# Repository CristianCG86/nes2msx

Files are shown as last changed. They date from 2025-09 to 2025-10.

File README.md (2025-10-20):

# NES2MSX

## Description
Converter for NES controllers (7-pin connector) to MSX standard.

## Acknowledgments
- David A. Mellis for his ATtiny board library (https://github.com/damellis/attiny).
- Josh Marinacci for his NESpad library (https://github.com/joshmarinacci/nespad-arduino).

## Why?
This project was born out of the difficulty of finding comfortable and accessible (and also affordable 🤑) controllers for MSX computers.  
But instead of destroying a NES controller, I decided to make this converter — that way I could also use other NES-style controllers such as those from 8Bitdo.

## Images
### PCB
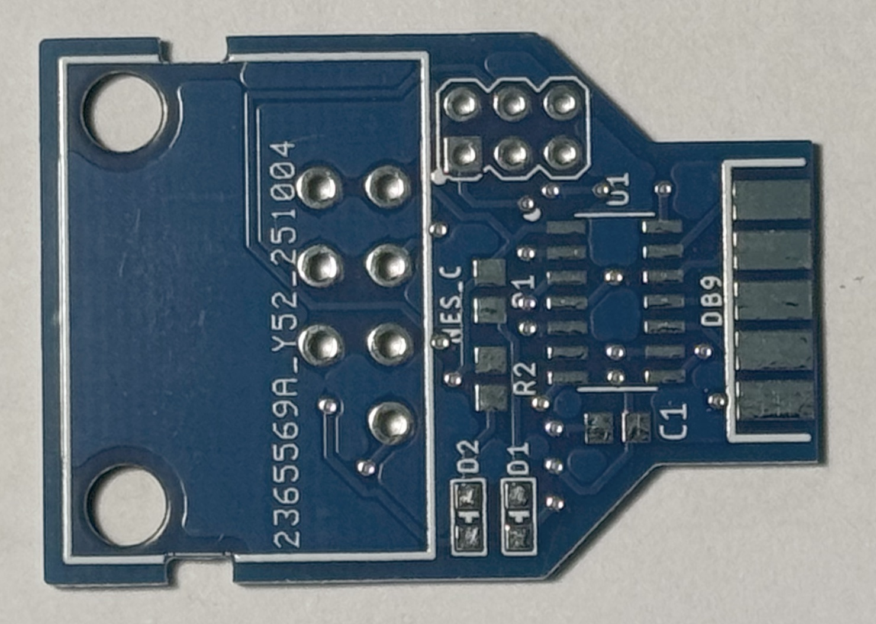
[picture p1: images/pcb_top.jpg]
PCB top side
  
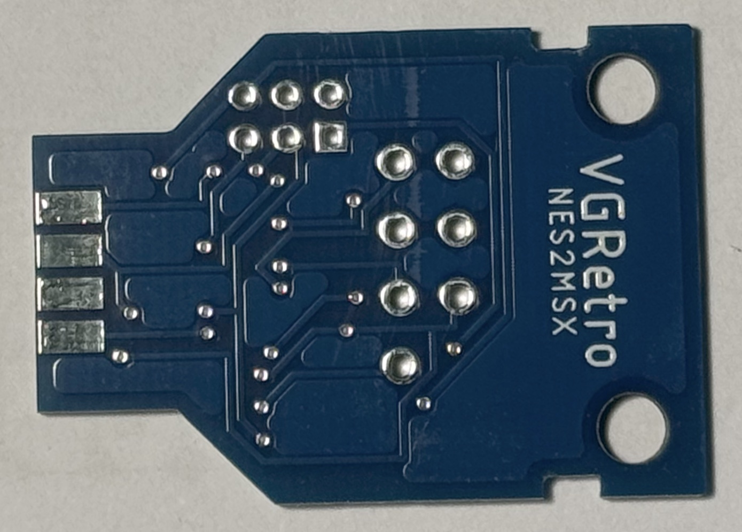
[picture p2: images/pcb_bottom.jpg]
PCB bottom side

### Assembled PCB
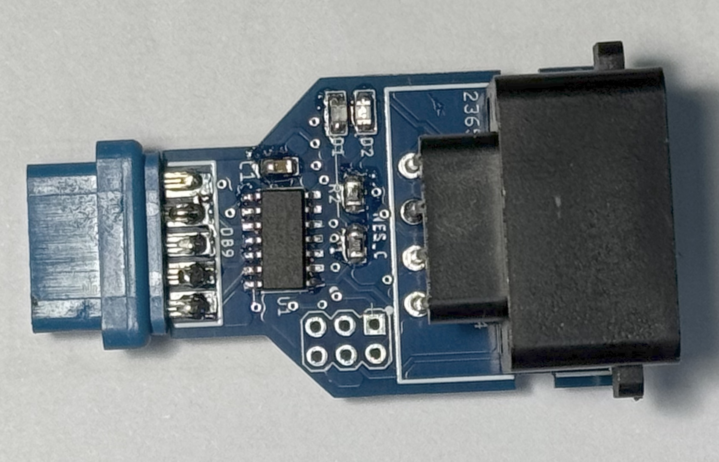
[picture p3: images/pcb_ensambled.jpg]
Assembled PCB top side


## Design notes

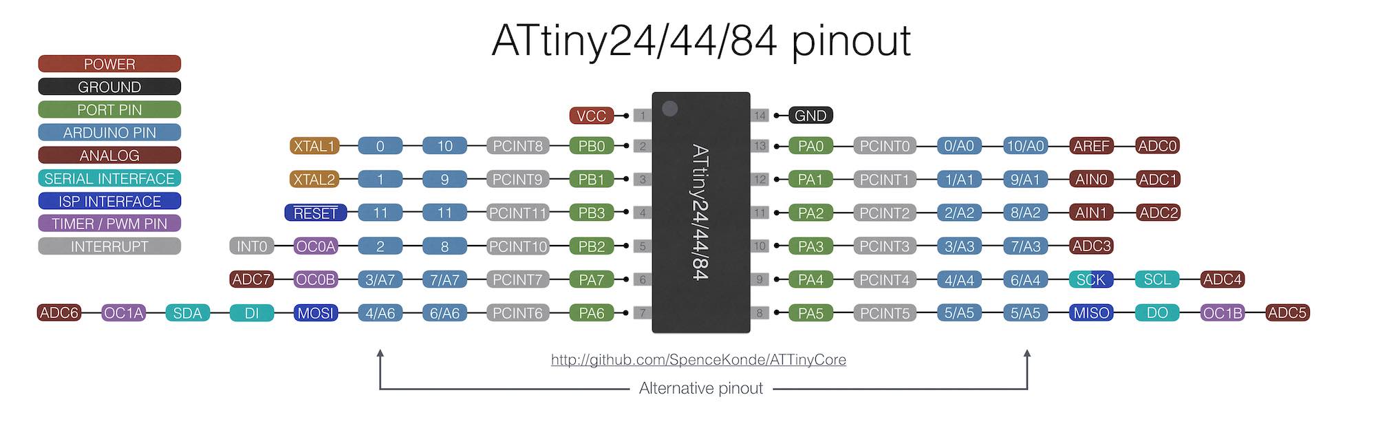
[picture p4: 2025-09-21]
attiny84_core.jpeg

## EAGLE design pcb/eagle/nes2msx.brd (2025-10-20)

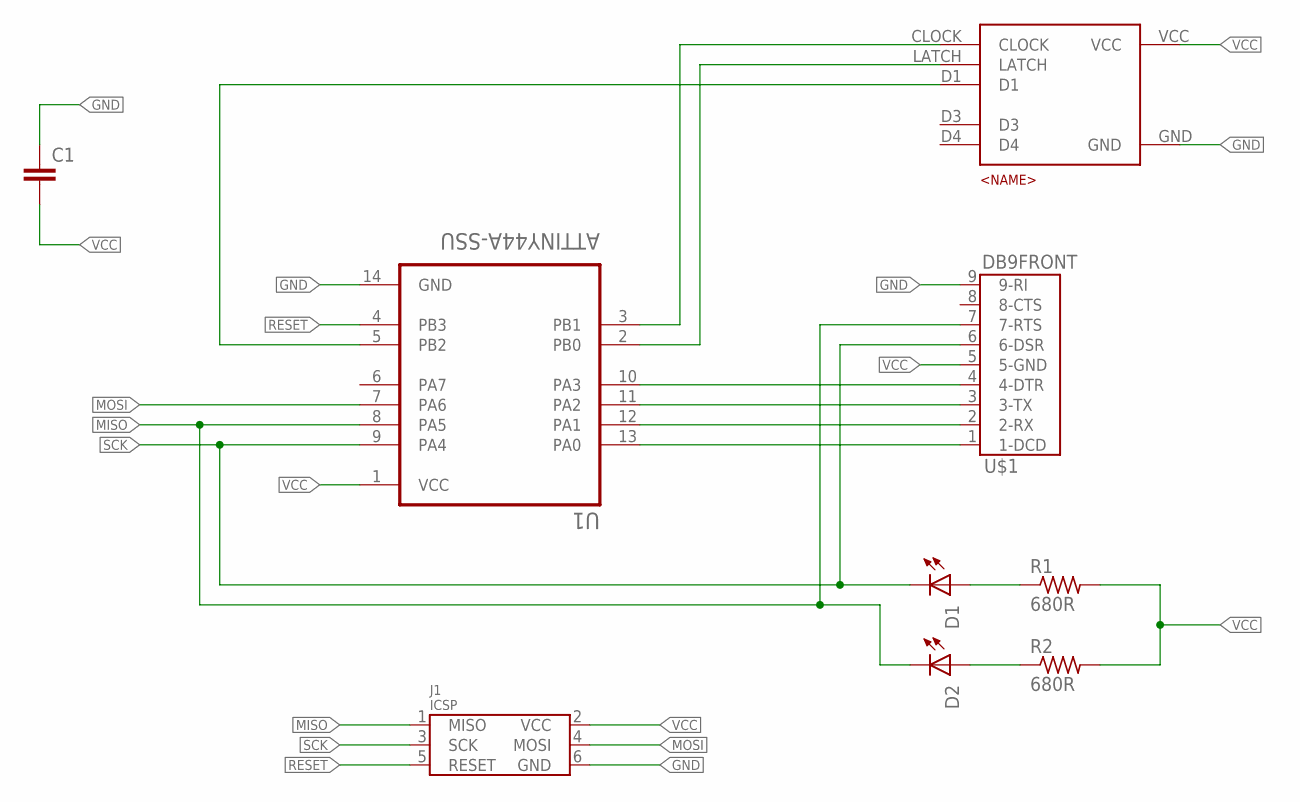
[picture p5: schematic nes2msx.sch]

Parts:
C1: C-EUC0805; C0805
D1, D2: LED-0805; 0805-LED
J1: ICSP; M03X2
R1, R2: 680R; R0805
U1: ATTINY44A-SSU; SOIC127P600X175-14N
U$1: DB9FRONT; DB9_FRONT
U$3: NES_CONTROLLERL; NES_CONTROLLER

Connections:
GND: C1.1, J1.6 (GND), U1.14 (GND), U$1.9 (9-RI), U$3.GND
MISO: D2.C, J1.1 (MISO), U1.8 (PA5), U$1.7 (7-RTS)
MOSI: J1.4 (MOSI), U1.7 (PA6)
unnamed: U1.13 (PA0), U$1.1 (1-DCD)
unnamed: U1.12 (PA1), U$1.2 (2-RX)
unnamed: U1.11 (PA2), U$1.3 (3-TX)
unnamed: U1.10 (PA3), U$1.4 (4-DTR)
unnamed: U1.3 (PB1), U$3.CLOCK
unnamed: U1.2 (PB0), U$3.LATCH
unnamed: U1.5 (PB2), U$3.D1
unnamed: D1.A, R1.1
unnamed: D2.A, R2.1
RESET: J1.5 (RESET), U1.4 (PB3)
SCK: D1.C, J1.3 (SCK), U1.9 (PA4), U$1.6 (6-DSR)
VCC: C1.2, J1.2 (VCC), R1.2, R2.2, U1.1 (VCC), U$1.5 (5-GND), U$3.VCC

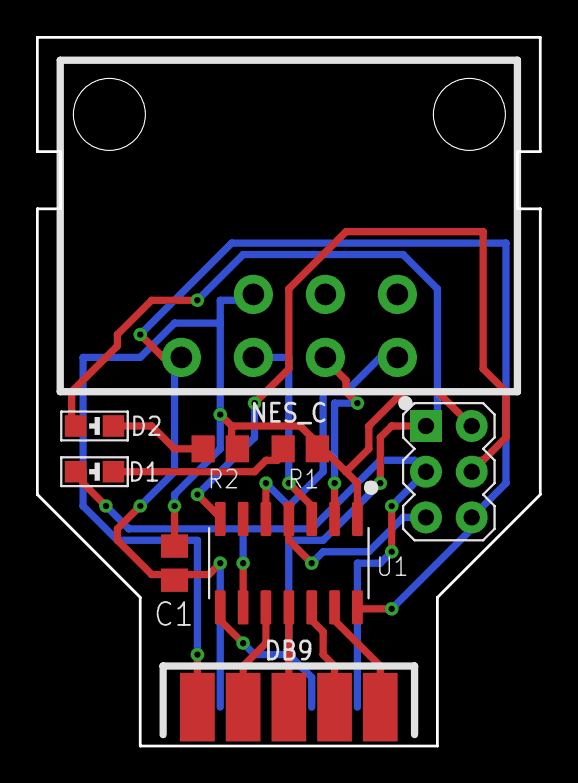
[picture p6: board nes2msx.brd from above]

Board: 2 copper layers, 27.9 x 39.4 mm, 9 parts (0 on the bottom side), 15 nets.

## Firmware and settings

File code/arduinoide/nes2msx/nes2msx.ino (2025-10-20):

#include "nespad.h"

/**
  ---- Prerequisites -------------------------------------------

  ATtiny boards from David A. Mellis
  https://github.com/damellis/attiny


  ---- Arduino IDE configuration -------------------------------

  Boards -> attiny -> ATtiny 24/44/84
  Clock -> Internal 8 MHz
  Processor -> ATtiny 44


  ---- Wire connection -----------------------------------------

  NES controller conection          MSX controller conection                                                        
          ____                           _____________      
         | 1   \                         \ 1 2 3 4 5 /      
         | 2  5 |                         \ 6 7 8 9 /       
         | 3  6 |                           -------         
         | 4  7 |                                           
          ------                      ┌─────┬───────────┐   
                                      │ MSX │   ATtiny  │   
    ┌─────┬───────────┐               ├─────┼───────────┤   
    │ NES │   ATtiny  │               │  1  │  PA0 [13] │   
    ├─────┼───────────┤               │  2  │  PA1 [12] │   
    │  1  │  VCC [1]  │               │  3  │  PA2 [11] │   
    │  2  │  PB1 [3]  │               │  4  │  PA3 [10] │   
    │  3  │  PB0 [2]  │               │  5  │  VCC [1]  │   
    │  4  │  PB2 [5]  │               │  6  │  PA5 [9]  │   
    │  5  │  GND [14] │               │  7  │  PA4 [8]  │   
    │  6  │  NC       │               │  8  │  NC       │   
    │  7  │  NC       │               │  9  │  GND [14] │   
    └─────┴───────────┘               └─────┴───────────┘   
*/

//  Turbo speed config
#define TURBO_INITIAL_SPEED 2
#define TURBO_MAX_SPEED 2
#define TURBO_INCREASE_SPEED 1

//  Turbo variables
uint8_t turbo_select_counter;
uint8_t turbo_select_toggler;
uint8_t turbo_select_pushed;
uint8_t turbo_select_speed;

uint8_t turbo_start_counter;
uint8_t turbo_start_toggler;
uint8_t turbo_start_pushed;
int8_t turbo_start_speed;

//  NES controller reader
NESpad nintendo = NESpad(10, 9, 8);

//  Input buffer
byte state = 0;

//  Output buffer
uint8_t state_processed;

void setup() {
  // Set port B as outputs and set to high
  DDRA = B11111111;
  PORTA = B11111111;

  // Initilization turbo vars
  turbo_select_counter = 0;
  turbo_select_toggler = 0;
  turbo_select_pushed = 0;

  turbo_start_counter = 0;
  turbo_start_toggler = 0;
  turbo_start_pushed = 0;
}

void loop() {
  
  state = nintendo.buttons();

  // Reorder buttons
  state_processed = ((state & (1 << 1)) << 3) |  // B -> bit4
           ((state & (1 << 0)) << 5) |  // A -> bit5
           ((state & (1 << 7)) >> 4) |  // R -> bit3
           ((state & (1 << 6)) >> 4) |  // L -> bit2
           ((state & (1 << 5)) >> 4) |  // D -> bit1
           ((state & (1 << 4)) >> 4);   // U -> bit0

  // Turbo SELECT (B)
  if(state & NES_SELECT) {
    turbo_select_pushed = 1;
  } else if(turbo_select_pushed == 1) {
    run_b_turbo();
    turbo_select_pushed = 0;
  }

  if(turbo_select_toggler == 1 && (turbo_select_counter >> 1) == 0) {
    state_processed = state_processed & 0b11101111;
  }

  // Turbo START (A)
  if(state & NES_START) {
    turbo_start_pushed = 1;
  } else if(turbo_start_pushed == 1) {
    run_a_turbo();
    turbo_start_pushed = 0;
  }

  if(turbo_start_toggler == 1 && (turbo_start_counter >> 1) == 0) {
    state_processed = state_processed & 0b11011111;
  }

  // Put data button into MSX port
  PORTA = ~(state_processed & 0b00111111);

  // Turbo counters
  turbo_select_counter++;
  if(turbo_select_counter > turbo_select_speed) turbo_select_counter = 0;
  
  turbo_start_counter++;
  if(turbo_start_counter > turbo_start_speed) turbo_start_counter = 0;
  
  delay(3);
}

//  Turbo operations (A)
void run_a_turbo() {
  if(turbo_start_toggler == 0) {
    turbo_start_toggler = 1;
    turbo_start_speed = TURBO_INITIAL_SPEED;
  } else if(turbo_start_speed < TURBO_MAX_SPEED) {
    turbo_start_speed += TURBO_INCREASE_SPEED;
  } else {
    turbo_start_toggler = 0;
    turbo_start_speed = 0;
  }
}

//  Turbo operations (B)
void run_b_turbo() {
  if(turbo_select_toggler == 0) {
    turbo_select_toggler = 1;
    turbo_select_speed = TURBO_INITIAL_SPEED;
  } else if(turbo_select_speed < TURBO_MAX_SPEED) {
    turbo_select_speed += TURBO_INCREASE_SPEED;
  } else {
    turbo_select_toggler = 0;
    turbo_select_speed = 0;
  }
}

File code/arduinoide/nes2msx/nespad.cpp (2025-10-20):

#include "nespad.h"
#include "Arduino.h"

NESpad::NESpad(int strobe, int clock, int data)
  : m_strobe (strobe),
  m_clock (clock),
  m_data (data)
  {
    pinMode(strobe, OUTPUT);
    pinMode(clock,  OUTPUT);
    pinMode(data, INPUT_PULLUP);
  }

byte NESpad::buttons(void)
{
  byte ret = 0;
  byte i;
  strobe();
  for (i = 0; i < 8; i++) {
    ret |= shiftin() << i;
  }
  return ~ret;
}

void NESpad::strobe(void)
{
  digitalWrite(m_strobe,HIGH);
  delayMicroseconds(12);
  digitalWrite(m_strobe,LOW);
}

byte NESpad::shiftin(void)
{
  byte ret = digitalRead(m_data);
  delayMicroseconds(12);
  digitalWrite(m_clock,HIGH);
  delayMicroseconds(12);
  digitalWrite(m_clock,LOW);
  return ret;
}

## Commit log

2025-09-21 First commit of local project nes2msx
    [nes2msx.GBL, nes2msx.GBO, nes2msx.GBP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]
2025-09-22 Refactor Gerber files for nes2msx PCB design
    [nes2msx.GBL, nes2msx.GBS, nes2msx.GKO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]
2025-10-20 Refactor code structure for improved readability and maintainability
    [nes2msx.brd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]
